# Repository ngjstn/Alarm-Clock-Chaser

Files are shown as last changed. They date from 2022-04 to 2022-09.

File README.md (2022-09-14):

# Alarm Clock Chaser 

### CPEN291 Project - 2021W Term 2 

> Group Members: Julian Wong, Justin Ng, Tayyib Chohan, Sam Dai 
 
 ---

### Project Overview

A lot of people have trouble getting out of bed in the morning and if you claim that you do not immediately snooze or dismiss your alarm, then lay in your bed and contemplate getting out of bed, you are a liar. 
Our solution is an alarm clock that drives away from you. At night you can set your alarm from the comfort of your bed but in the morning you are forced to get up and chase down the alarm clock ensuring you get out of bed to start your day. 

The alarm can be set through the web user interface, which allows for a time and song choice setting to be sent to the device. Once it's time for the alarm to ring, the chosen song begins playing and the pathing algorithm will intiiate, causing the alarm device to begin driving away and avoiding any obstacles in it's path. When the robot has finally been caught, deactivating it can be done by pressing the button on the top of the chassis. Once pressed, all movement and audio will stop, and the camera that is attached to the Raspberry Pi will take a picture of the user, and upload this image to Imgur, a media sharing website. A url containing the image will be sent back to the web server to be viewed. 

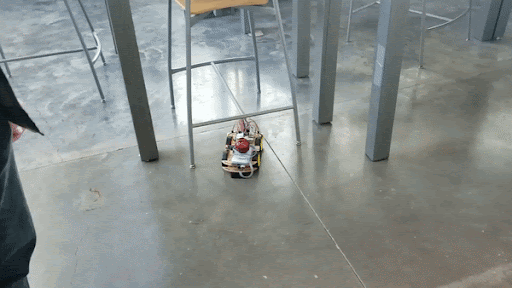
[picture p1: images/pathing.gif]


---

### Component List

| Part | Description | Quantity |
| --- | --- | --- |
| Raspberry Pi Model 3 B+ | Primary computing device for alarm functionality | 1 | 
| HC-SR04 | Ultrasonic sensor for proximity detection | 3 | 
| Pi Camera Rev 1.3 | RPI camera module | 1 | 
| L298N2 | DC motor drive controller | 1 | 
| Push Button | Alarm deactivation sequence | 1 | 
| Adafruit 1.8'' TFT Display | LCD display for the current time | 1 |
| Breadboard | Solderless connections for the HC-SR04 | 1 |
| Proto Board | Soldered connections for the TFT display and push button | 1 | 
| Acrylic Car Chassis | Main body of the robot | 1 | 
| X-Mini Speaker | Audio output for the alarm sound | 1 | 
| Power Bank | Power supply for the Raspberry Pi | 1 | 
| 1.5V AA Battery | Power supply for DC motors | 4 |
| 10kOhm Resistor | Pull down resistor circuit | 1 |

---

### Robot Chassis

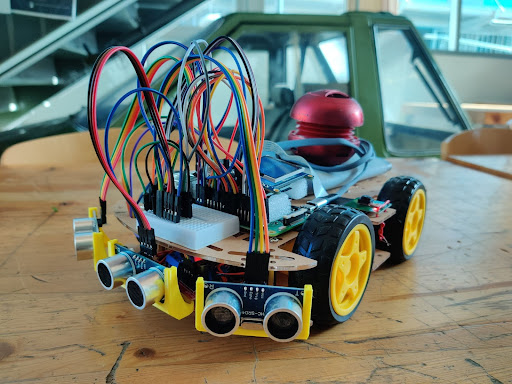
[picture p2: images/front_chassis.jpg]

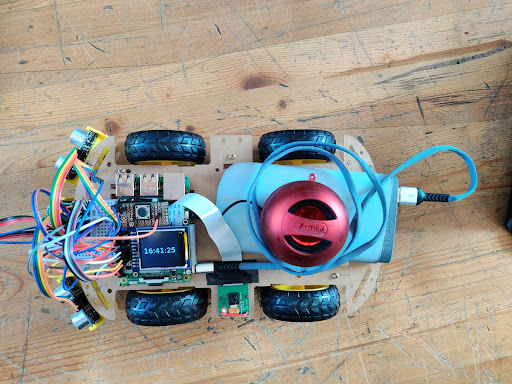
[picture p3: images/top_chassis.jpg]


---

### Block Diagrams 

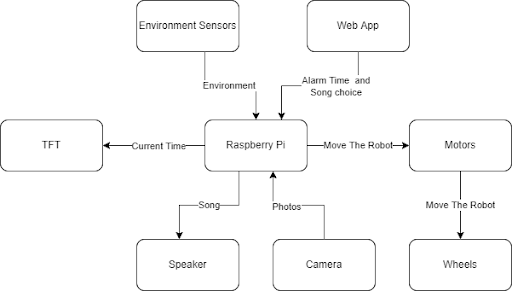
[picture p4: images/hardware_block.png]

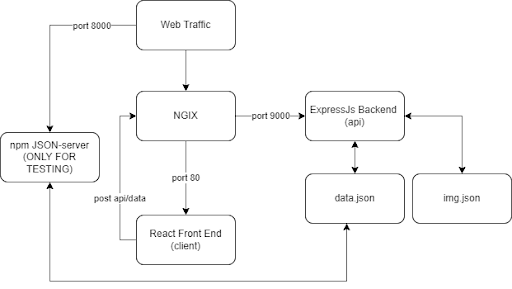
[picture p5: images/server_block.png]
 
 
 ---

### Fritizing Diagram

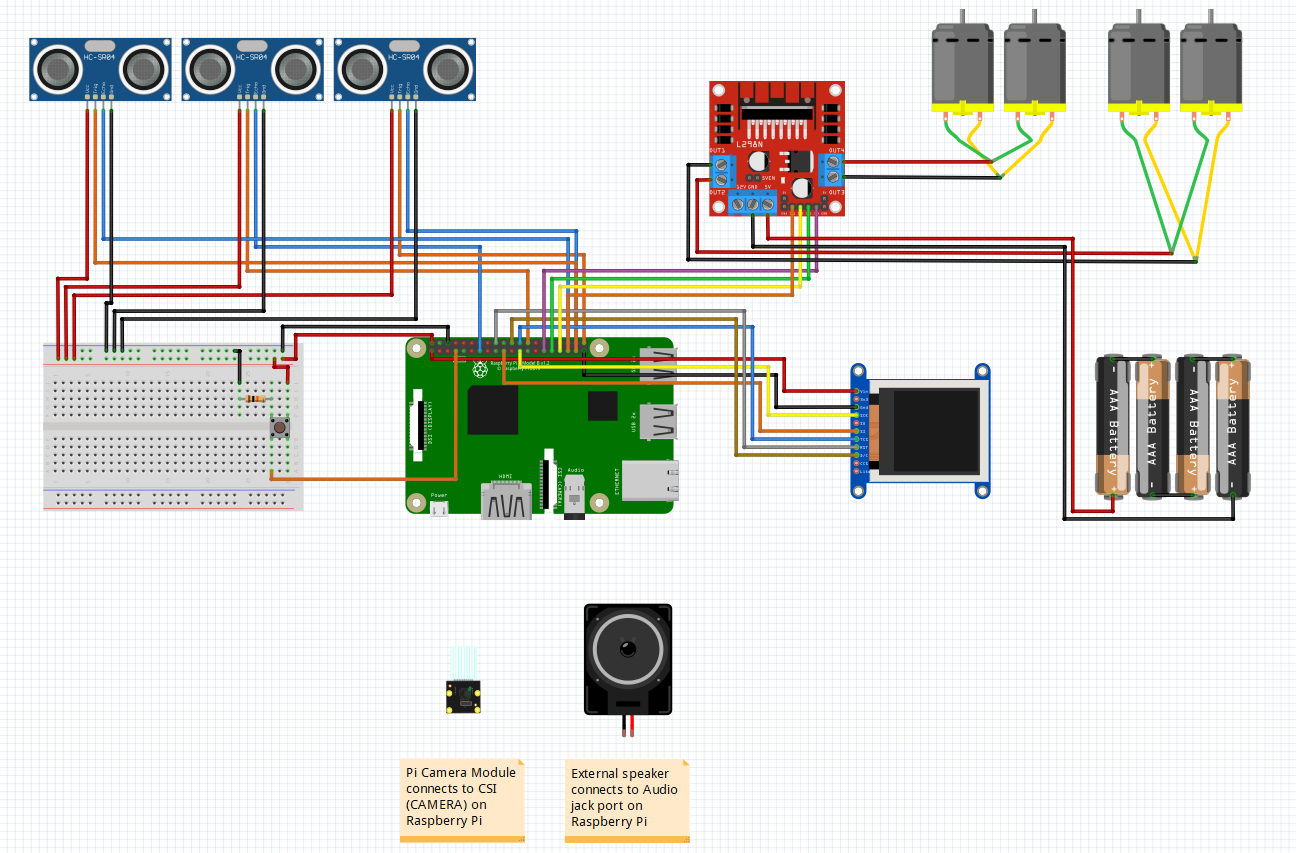
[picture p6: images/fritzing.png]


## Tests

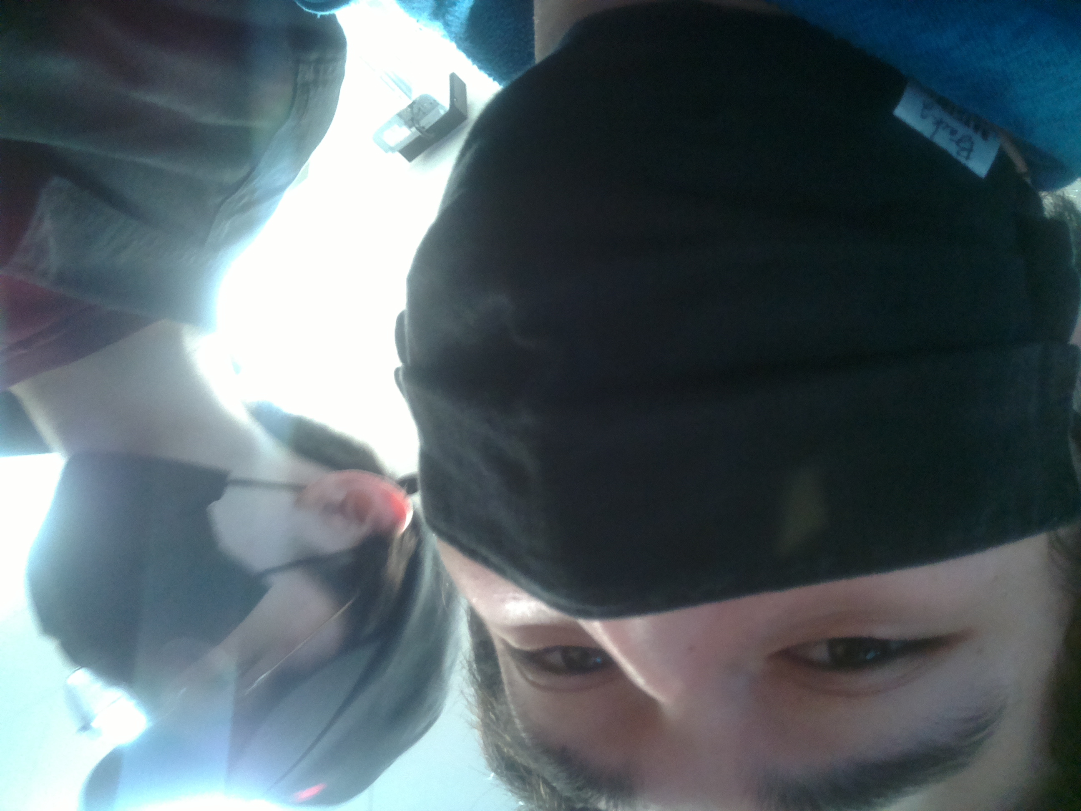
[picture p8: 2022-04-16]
RPI_testing/image.jpg

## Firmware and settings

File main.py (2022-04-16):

from multiprocessing import Process
import time 
from picamera import PiCamera
import board 
import requests
import datetime 
from digitalio import DigitalInOut, Direction, Pull
from motorControl import*
from clockBg import clockBg
from updateSong import updateSong
from getDict import getDict
from uploadImgur import uploadImg

# intialize camera object and define upload image path
camera = PiCamera()
camera.capture('/home/pi/Desktop/pi_camera/image.jpg')

# starts the clock display process in the background (check clockBg.py)
clock = Process(target = clockBg) 
clock.start() 

# define push button settings
button = DigitalInOut(board.D4) 
button.direction = Direction.INPUT
button.pull = Pull.DOWN

newDay = True;

# sends server request to get the dictionary data 
x = getDict()
hour = x['hour']
minute = x['minute']
print(hour)
print(minute)

# define time settings
local_timezone = datetime.timezone(datetime.timedelta(hours=+17))  
given_time = datetime.datetime.strptime(str(hour) + ':' + str(minute), "%H:%M").time()

# check if we have entered a new day 
if (given_time < datetime.datetime.now().astimezone(local_timezone).time()): 
    newDay = False 

# lookup which song was received in the server request (check updateSong.py)
song = updateSong(x['song'])

# main functionality loop
while True: 
    old_time = datetime.datetime.now().astimezone(local_timezone).time() 
    current_time = datetime.datetime.now().astimezone(local_timezone).time() 
    print(current_time)

    # check if the alarm time has been met or if we aren't in a new day, then stay in loop
    while given_time > current_time or not newDay: 
        time.sleep(0.01)
        old_time = current_time
        current_time = datetime.datetime.now().astimezone(local_timezone).time()
        print(current_time) 
        if old_time > current_time: 
            newDay = True 

        # send server request to check for any new alarms
        x2 = getDict()

        # check if the new alarm is today or tomorrow 
        if x2 != x:
            newDay = True
            hour = x2['hour']
            minute = x2['minute'] 
            x = x2 
            given_time = datetime.datetime.strptime(str(hour) + ':' + str(minute), "%H:%M").time()
            if (given_time < current_time): 
                newDay = False 
            song = updateSong(x2['song'])

    newDay = False
    print('exit while loop')
    song.play()
    
    # short delay to ensure song is actually playing
    while song.is_playing() == 0: 
        time.sleep(0.01)

    # waits for alarm button to be pressed
    while not button.value: 
        time.sleep(0.01)

        # intialize movement pathing algorithm
        pathingAlg()

        # if song finishes before button is pressed, loop back to beginning of the song
        if song.is_playing() == 0: 
            print("song ended... restarting")
            song.stop()
            song.play()
            while song.is_playing() == 0: 
                time.sleep(0.01)

    song.stop() 
    stop()

    # takes picture 
    print("button pushed")
    camera.capture('/home/pi/Desktop/image.jpg')

    # uploads image to Imgur, sends post request URL to server
    try:
        url = 'http://cpen291-27.ece.ubc.ca/api/img'
        myobj = {'url': uploadImg()} 
        x = requests.post(url, data= myobj) 
        
    except: 
        print("Error uploading image")

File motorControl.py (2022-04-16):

import digitalio 
import board 
import time
import adafruit_hcsr04
import random

sonarRight = adafruit_hcsr04.HCSR04(trigger_pin=board.D17, echo_pin=board.D27)
sonarLeft = adafruit_hcsr04.HCSR04(trigger_pin=board.D21, echo_pin=board.D20)
sonarMiddle = adafruit_hcsr04.HCSR04(trigger_pin=board.D16, echo_pin=board.D26)

leftForward = digitalio.DigitalInOut(board.D5)
leftReverse = digitalio.DigitalInOut(board.D6)
rightForward = digitalio.DigitalInOut(board.D19)
rightReverse = digitalio.DigitalInOut(board.D13)

leftForward.direction = digitalio.Direction.OUTPUT
leftReverse.direction = digitalio.Direction.OUTPUT
rightForward.direction = digitalio.Direction.OUTPUT
rightReverse.direction = digitalio.Direction.OUTPUT

leftForward.value = False
leftReverse.value = False
rightForward.value = False
rightReverse.value = False

def forward():
    leftForward.value = True
    leftReverse.value = False
    rightForward.value = True
    rightReverse.value = False
    
def right():
    leftForward.value = True
    leftReverse.value = False
    rightForward.value = False
    rightReverse.value = True
    
def left():
    leftForward.value = False
    leftReverse.value = True
    rightForward.value = True
    rightReverse.value = False
    
def reverse():
    leftForward.value = False
    leftReverse.value = True
    rightForward.value = False
    rightReverse.value = True

def stop():
    leftForward.value = False
    leftReverse.value = False
    rightForward.value = False
    rightReverse.value = False

def leftTurn(): 
    leftForward.value = False
    leftReverse.value = True
    rightForward.value = True
    rightReverse.value = False
    time.sleep(0.4)

    rightForward.value = False 
    leftReverse.value = False 

def rightTurn(): 
    leftForward.value = True
    leftReverse.value = False
    rightForward.value = False
    rightReverse.value = True
    time.sleep(0.4)

    rightReverse.value = False 
    leftForward.value = False 

def sensorRead(sensor):
    dist = 100 
    try: 
        dist = sensor.distance 
    except RuntimeError: 
        pass 
    return dist 

def pathingAlg(): 
    #forward()
    leftDist = sensorRead(sonarLeft)
    rightDist = sensorRead(sonarRight) 
    middleDist = sensorRead(sonarMiddle)
    print("left: " + str(leftDist))
    print("right: " + str(rightDist))
    print("middle: " + str(middleDist))

    if rightDist < leftDist and rightDist < 15:
        while rightDist < 15: 
            print("1")
            rightDist = sensorRead(sonarRight)
            leftTurn()
    elif leftDist < rightDist and leftDist < 15: 
        while leftDist < 15:
            print("2")
            leftDist = sensorRead(sonarLeft)
            rightTurn()
    elif middleDist < 15: 
        if random.choice(("left", "right")) == "left": 
            
            print("3")
            leftTurn()
        else: 
            print("4")
            rightTurn()
    else: 
        forward()
    time.sleep(0.01)
   


# while True: 
#     forward()
#     time.sleep(2)
#     stop()
